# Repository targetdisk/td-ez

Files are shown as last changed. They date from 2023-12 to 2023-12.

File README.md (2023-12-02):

# Targetdisk Cable Firmware
### for Cypress EZ-USB FX2

This firmware is for the Cypress CY7C68013 EZ-USB FX2 chip (well for two
FX2 chips, actually).

## What is this?

My USB target disk solution allows any UEFI-compatible motherboard to share all
attached block storage devices with another computer as if they were just regular
USB mass storage devices.

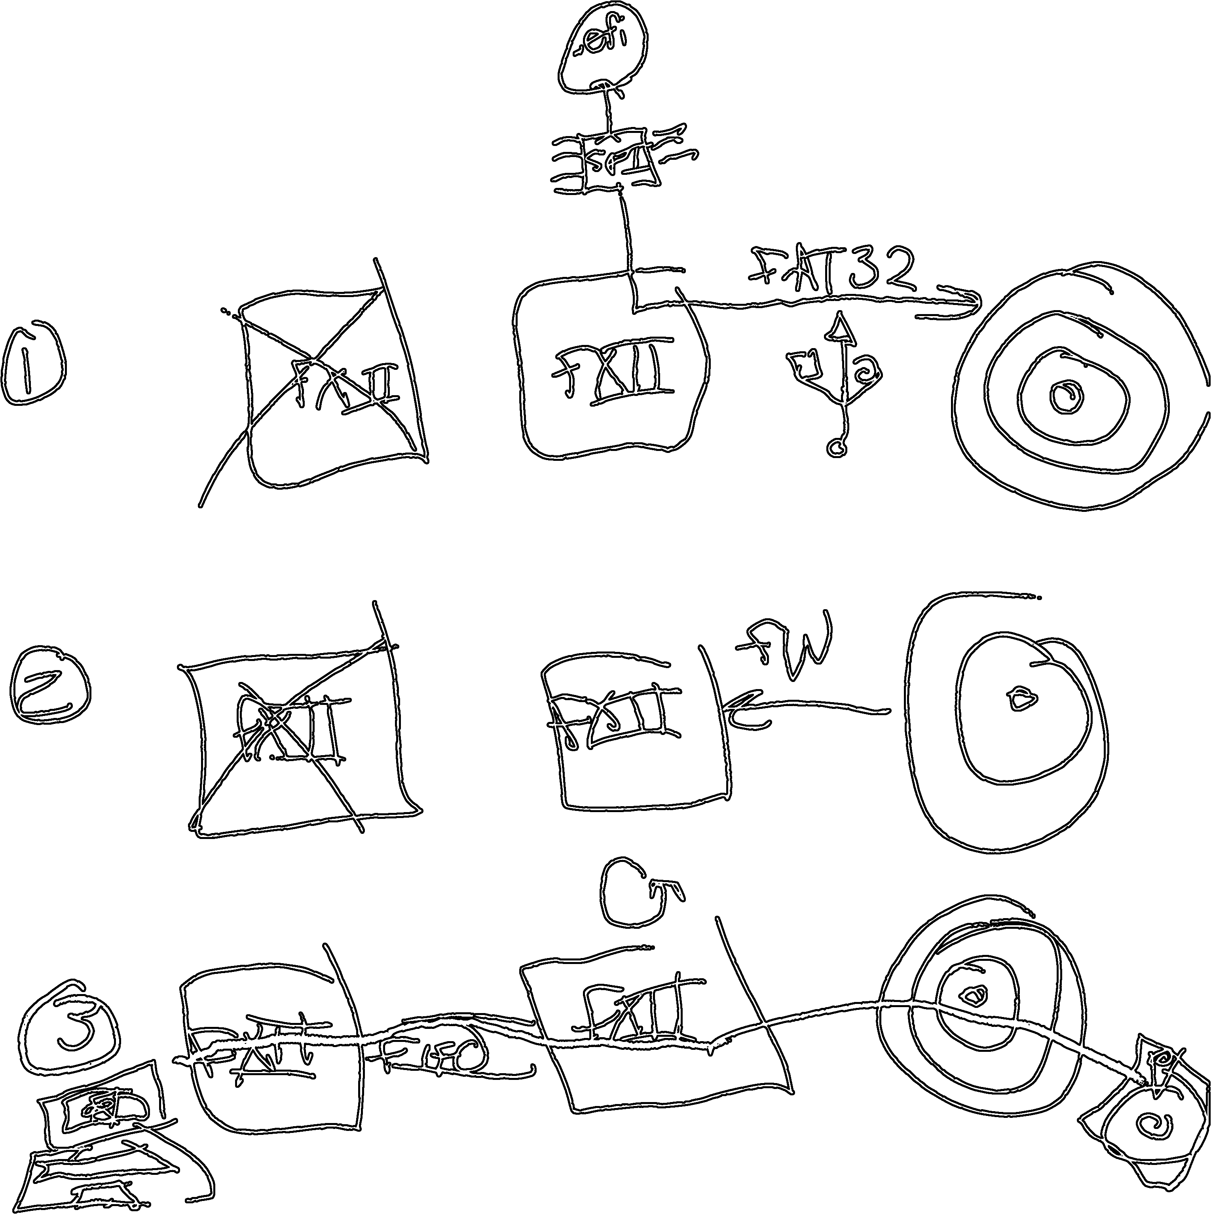
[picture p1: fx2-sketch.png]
diagram of how this all works


1. The business end of our dongle device attaches to a target computer.  The
   target computer loads and executes
   [the Targetdisk UEFI runtime](https://github.com/targetdisk/targetdisk-efi)
   hosted on the business end of our dongle.
2. The UEFI runtime on the target device reflashes the business end of our
   dongle device with FIFO-establishing firmware.
3. After the business end of the dongle reboots, it lets the other FX2 know
   that it's time to wake up and establish our hardware FIFO.  The hardware
   FIFO then begins to proxy SCSI commands from the mass storage interface end
   of our dongle to the target computer's UEFI runtime.

## Flashing
Note that I have only successfully loaded firmware with the Python `fx2tool`
so far.  More details soon!

## See Also
- The [libfx2 documentation](https://libfx2.readthedocs.io/en/stable/introduction.html)
- My work-in-progress
  [Targetdisk UEFI runtime](https://github.com/targetdisk/targetdisk-efi)
- The [original CY7C68013 EZ-USB FX2 USB Microcontroller datasheet](https://www.keil.com/dd/docs/datashts/cypress/cy7c68xxx_ds.pdf)
- Infineon's [updated datasheet](https://www.infineon.com/dgdl/Infineon-CY7C68013A_CY7C68014A_CY7C68015A_CY7C68016A_EZ-USB_FX2LP_USB_Microcontroller_High-Speed_USB_Peripheral_Controller-DataSheet-v3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)
- The [FX2 Technical Reference Manual](https://www.infineon.com/dgdl/Infineon-EZ-USB_TECHNICAL_REFERENCE_MANUAL-AdditionalTechnicalInformation-v08_00-EN.pdf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)

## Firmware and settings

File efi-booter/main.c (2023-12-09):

#include <fx2delay.h>
#include <fx2regs.h>
#include <fx2usb.h>

#include "booter-usb.h"
#include "efi_scsi.h"

volatile bool pending_ep6_in;

void isr_IBN(void) __interrupt {
  pending_ep6_in = true;
  CLEAR_USB_IRQ();
  NAKIRQ = _IBN;
  IBNIRQ = _IBNI_EP6;
}

int main() {
  CPUCS = _CLKSPD1;

  REVCTL = _ENH_PKT | _DYN_OUT;

  /* According to the technical reference manual, this macro is magic.  Trust.  */
  SYNCDELAY;

  FIFORESET = _NAKALL;

  /* Enable endpoint |  BULK TYPE | OUT direction | double-buffered */
  EP2CFG = _VALID | _TYPE1 | _BUF1;
  EP2CS = 0;  /* Reset Endpoint control and status bit field register */

  EP6CFG = _VALID | _TYPE1 | _DIR | _BUF1;
  EP6CS = 0;

  /* Disable endpoints 4 and 8 */
  EP4CFG &= ~_VALID;
  EP8CFG &= ~_VALID;

  /* Enable IN-BULK-NAK interrupts for EP6 */
  IBNIE = _IBNI_EP6;
  NAKIE = _IBN;

  /* Reset the hardware FIFOs */
  SYNCDELAY;
  FIFORESET = _NAKALL|2;
  SYNCDELAY;
  OUTPKTEND = _SKIP|2;
  SYNCDELAY;
  OUTPKTEND = _SKIP|2;
  SYNCDELAY;
  FIFORESET = _NAKALL|6;
  SYNCDELAY;
  FIFORESET = 0;

  efi_spi_init();

  // Re-enumerate, to make sure our descriptors are picked up correctly.
  usb_init( true );

  for ( ;; )
  {
    /* Handle OUT requests from host */
    if ( !( EP2CS & _EMPTY ) )
    {
      uint16_t length = ( EP2BCH << 8 ) | EP2BCL;
      if ( usb_mass_storage_bbb_bulk_out( &usb_mass_storage_state, EP2FIFOBUF, length ) )
      {
        EP2BCL = 0;
      }
      else
      {
        EP2CS  = _STALL;
        EP6CS  = _STALL;
      }
    }

    if ( pending_ep6_in )
    {
      __xdata uint16_t length;
      if ( usb_mass_storage_bbb_bulk_in( &usb_mass_storage_state, EP6FIFOBUF, &length ) )
      {
        if ( length > 0 )
        {
          EP6BCH = length >> 8;
          SYNCDELAY;
          EP6BCL = length;
        }
      }
      else
      {
        EP6CS  = _STALL;
      }

      pending_ep6_in = false;
    }
  }
}

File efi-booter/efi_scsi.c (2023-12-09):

#include <stdint.h>
#include <stdbool.h>
#include <stddef.h>
#include <string.h>
#include <fx2lib.h>
#include <fx2spiflash.h>
#include <fx2uf2.h>
#include <scsi.h>

#include "efi_scsi.h"

static enum scsi_op_code current_op;
static enum scsi_sense_key sense_key;
static uint32_t block_index;
static uint32_t blocks_left;
static uint32_t block_addr;

static DEFINE_SPIFLASH_FNS( spiflash, CS_PIN, SCK_PIN, MISO_PIN, MOSI_PIN )

void efi_spi_init( void )
{
  OEA = OEA_SPI;
  spiflash_init();
}

bool efi_scsi_command(uint8_t lun, __xdata uint8_t *buffer, uint8_t length) __reentrant
{
  __xdata struct scsi_command *command = (__xdata struct scsi_command *)buffer;
  lun;

  // Here, we generally ignore the Allocation length field when validating the commands,
  // since this is already handled on the USB MSC BBB level.

  if(command->op_code == SCSI_OPERATION_TEST_UNIT_READY &&
            length >= sizeof(command->op_code) + sizeof(command->test_unit_ready)) {
    goto success;
  } else if(command->op_code == SCSI_OPERATION_REQUEST_SENSE &&
            length >= sizeof(command->op_code) + sizeof(command->request_sense)) {
    if(command->request_sense.desc == 0) {
      goto success;
    }
  } else if(command->op_code == SCSI_OPERATION_INQUIRY &&
            length >= sizeof(command->op_code) + sizeof(command->inquiry)) {
    if(command->inquiry.evpd == 0 && command->inquiry.page_code == 0) {
      goto success;
    }
  } else if(command->op_code == SCSI_OPERATION_PREVENT_ALLOW_MEDIUM_REMOVAL &&
            length >= sizeof(command->op_code) + sizeof(command->prevent_allow_medium_removal)) {
    goto success;
  } else if(command->op_code == SCSI_OPERATION_READ_CAPACITY &&
            length >= sizeof(command->op_code) + sizeof(command->read_capacity)) {
    goto success;
  } else if(command->op_code == SCSI_OPERATION_READ_10 &&
            length >= sizeof(command->op_code) + sizeof(command->read_10)) {
    block_index = bswap32(command->read_10.logical_block_address);
    blocks_left = bswap32(command->read_10.transfer_length);
    goto success;
  } else if(command->op_code == SCSI_OPERATION_WRITE_10 &&
            length >= sizeof(command->op_code) + sizeof(command->write_10)) {
    block_index = bswap32(command->write_10.logical_block_address);
    blocks_left = bswap32(command->write_10.transfer_length);
    goto success;
  }

  current_op = 0;
  sense_key  = SCSI_SENSE_ILLEGAL_REQUEST;
  return false;

success:
  current_op = command->op_code;
  return true;
}

bool efi_scsi_data_out( uint8_t lun, __xdata const uint8_t *buffer, uint16_t length ) __reentrant
{
  lun;

  if(current_op == SCSI_OPERATION_WRITE_10) {
    if(blocks_left == 0)
      return false;
    if(length != 512)
      return false;

    block_addr = block_index * BYTES_PER_SECTOR;
    spiflash_pp( block_index, buffer, BYTES_PER_SECTOR );

    block_index++;
    blocks_left--;
    if(blocks_left > 0)
      return true;

    goto done;
  }

  return false;

done:
  current_op = 0;
  return true;
}

bool efi_scsi_data_in (uint8_t lun, __xdata uint8_t *buffer, uint16_t length) __reentrant
{
  lun;

  if(current_op == SCSI_OPERATION_REQUEST_SENSE) {
    __xdata struct scsi_sense_data_fixed *data =
      (__xdata struct scsi_sense_data_fixed *)buffer;
    xmemclr(buffer, length);

    data->response_code = SCSI_SENSE_CURRENT_ERROR_FIXED_FORMAT;
    data->sense_key     = sense_key;

    sense_key = SCSI_SENSE_NO_SENSE;
    goto done;
  } else if(current_op == SCSI_OPERATION_INQUIRY) {
    __xdata struct scsi_inquiry_data *data =
      (__xdata struct scsi_inquiry_data *)buffer;
    xmemclr(buffer, length);

    data->additional_length = sizeof(struct scsi_inquiry_data) -
      (offsetof(struct scsi_inquiry_data, additional_length) +
       sizeof(data->additional_length));

    // SBC-2 (Direct access block device).
    // It would be more fitting to use RBC here, but Windows does not understand
    // how to talk to that (even though RBC is basically boneless SBC...)
    data->peripheral_device_type = 0x00;

    /* We're a removable device. */
    data->rmb = true;

    /* Our identification. */
    xmemcpy( data->t10_vendor_identification, (__xdata void *)"Andrea R",          8 );
    xmemcpy( data->product_identification,    (__xdata void *)"targetdisk (SPI)",  16 );
    xmemcpy( data->product_revision_level,    (__xdata void *)"A0  ",              4 );

    goto done;
  }
  else if ( current_op == SCSI_OPERATION_READ_CAPACITY )
  {
    __xdata struct scsi_read_capacity_data *data =
      (__xdata struct scsi_read_capacity_data *)buffer;

    data->returned_logical_block_address  = bswap32(TOTAL_SECTORS - 1);
    data->block_length_in_bytes           = bswap32(512);

    goto done;
  }
  else if ( current_op == SCSI_OPERATION_READ_10 )
  {
    if ( blocks_left == 0 )
      return false;
    if ( length != 512 )
      return false;

    block_addr = block_index * BYTES_PER_SECTOR;
    spiflash_read( block_index, buffer, BYTES_PER_SECTOR );

    block_index++;
    blocks_left--;
    if ( blocks_left > 0 )
      return true;

    goto done;
  }

  return false;

done:
  current_op = 0;
  return true;
}

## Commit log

2023-11-09 [NEW] include: Added EZ-USB™ register defs
2023-12-01 [NEW] efi-booter: Check in initial unfinished SPI flash drive code
    I usually don't check in non-working code to git, but this is really
    getting out of hand...
    The efi-booter FX2 firmware is the code that serves up a USB mass
    storage device using an external SPI flash chip as a backing store (well
    it will once it's finished). The target computer uses this drive to
    load the targetdisk UEFI runtime before reflashing its half of the FX2
    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
2023-12-03 [NEW] hw: Add initial revA hardware design
    This is still a work in progress, but KiCAD and I are working on it.
    [revA.kicad_pcb, revA.kicad_sch]
2023-12-03 hw: Finish rough board schematic (except for FIFOs)
    These schematics are subject to change, but this is the gist of what I
    am trying to do here. I have a pretty good idea of the form factor I'm
    shooting for, and I know what footprints I want for the big-ticket items
    already (for the most part). I am operating under the assumption that I
    can share a single EEPROM chip between the two FX2 devices, since only
    one of them should ever be loading the USB IDs and bootloader from the
    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
    [revA.kicad_sch]
2023-12-05 hw: Move all SPI to port A
    [revA.kicad_sch]
2023-12-09 efi-booter: change SPI pins, fill out helper fns
2023-12-09 efi-booter: Compile efi_scsi sources, fix them some more
    [efi_scsi.c]
2023-12-14 Makefile: Create blank SPI flash images
2023-12-15 Makefile: EFI runtime and ESP target improvements
    Make img_data.h generation seamless, fix additional issues with output
    directories and EFI targets.
    I have also added some scripts to add an empty FAT filesystem to our
    blank SPI disk image.
2023-12-15 Makefile: Programmatically populate SPI image (Linux only)
    Uses loop devices to mount and add files to the SPI flash image.
    I will probably hack in support for doing this in Mac OS X/OS X/macOS
    later on.
